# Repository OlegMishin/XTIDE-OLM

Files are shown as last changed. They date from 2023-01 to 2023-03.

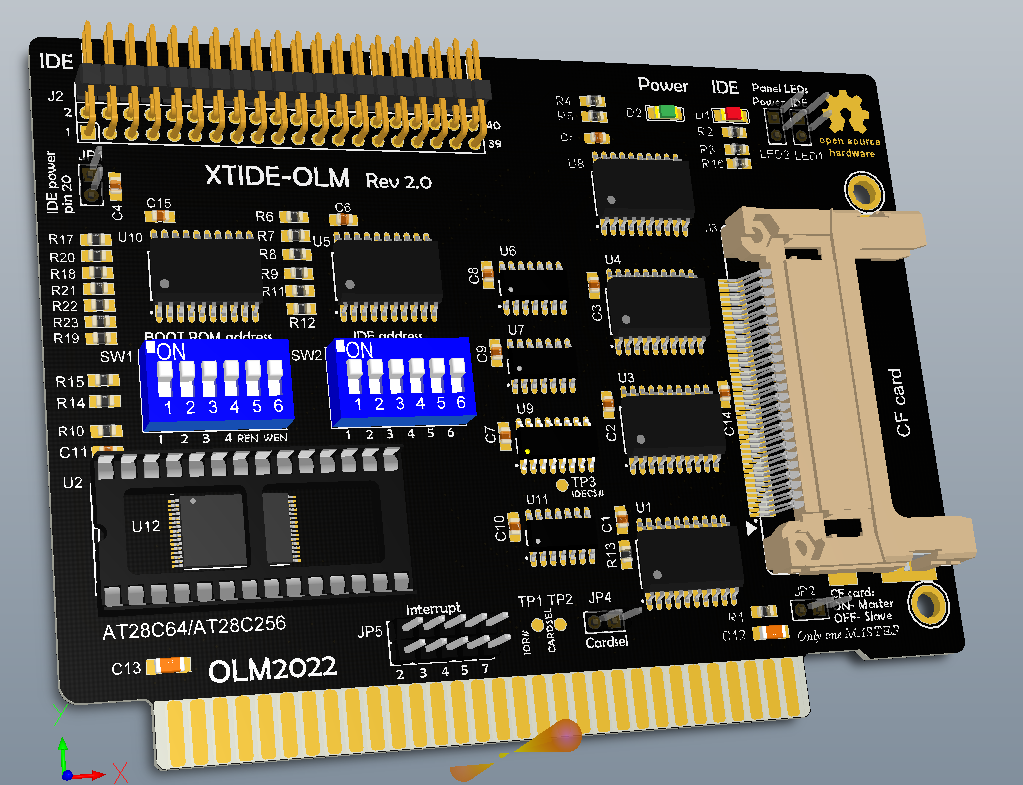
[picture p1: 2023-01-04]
3d.png

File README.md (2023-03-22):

# XTIDE-OLM
A Compact Flash to ISA bus adapter with XTIDE BIOS support

Based on Glitch Works XT-IDE: https://github.com/glitchwrks/xt_ide

So far tested with SST39F010 and AT28C64 Flash(writen with "xtidecfg.com") and 27C512 burned with TL866 programmer.
Works on PC-XT and PC-AT. Tested with 8088, 286, 386 and 486 computers. 

Designed for Keystone 9202 bracket. The bracket has no window for CF card, so it must be drilled manually.
Also the bracket can be 3D-printed. The 3D model is in "XTIDE_OLM-bracket.STL" file.

For 32K BIOS ROM R14 and R15 need to be be removed and mounted for 8K ROM (e.g. 2864).
There is no issue if R14 and R15 unmounted with 8K ROM, but in this case BIOS ROM window is 32K and configured by SW1.1 and SW1.2 only.

# XTIDE BIOS:
Can be obtained here: https://www.xtideuniversalbios.org/

# How to configure:
1. Set BIOS and I/O addresses by DIP switches SW1 and SW2.
2. Configure BIOS using XTIDECFG.
- Start XTIDECFG
- Select "Load BIOS from file" and load BIOS you want to flash.
- Go to "Configure XTIDE Universal BIOS". Usually I select "Auto configure"(CF card must be inserted) or manually configure it as needed.
- Go to "Flash EEPROM" and select "2864" or "SS39SFxx"(depends on installed Flash IC) and flash the BIOS.
- Reboot your computer.



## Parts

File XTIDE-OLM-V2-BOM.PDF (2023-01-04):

Bill of Materials | | XTIDE-OLM-V2
Revision | 2.0
Created by | OLM
Creation date | 01.01.2023 | 0:43:12
Print date | 01.01.2023 | 0:43:19
No. | QuantityDesignator | | Comment | Value | Part footprint | Part # | Manufacturer | Description
0 | 13 | C1, C2, C3, C4, C5, C6, C7, C8, C9, C10, C11, C14, C15 | Capacitor | 100nF | 0805 | K104K15X7RF5TH5 | Vishay Intertech | Ceramic capacitor SMD
1 | 2 | C12, C13 | Capacitor | 10uF | 1206 | CD1H106KC9IER2F100 | Dersonic | Ceramic capacitor SMD
2 | 1 | D1 | LED | 15-21/R6C-FQ1R1B/2T | 1206 | 15-21/R6C-FQ1R1B/2T | Everlight Elec | LED SMD 1206 Red
3 | 1 | D2 | LED | 24-21/G6C-BM1N2L/2A | 1206 | 24-21/G6C-BM1N2L/2A | Everlight Elec | LED SMD 1206 Green
4 | 1 | J3 | CF card socket | CFH-38690R | CF_CARD | CFH-38690R | UMAX | Compact Flash Card Socket
5 | 3 | R1, R4, R5 | Resistor | 1k | 0805 | ERJ6GEYJ102V | Panasonic | Resistor SMD 0805
6 | 16 | R2, R6, R7, R8, R9, R10, R11, R12, R13, R17, R18, R19, R20, R21, R22, R23 | Resistor | 10k | 0805 | ERJ6GEYJ103V | Panasonic | Resistor SMD 0805
7 | 1 | R3 | Resistor | 0R | 0805 | AC0805FR-070RL | YAGEO | Resistor SMD 0805
8 | 1 | R16 | Resistor | 470 | 0805 | ERJ6GEYJ471V | Panasonic | Resistor SMD 0805
9 | 2 | U1, U8 | 74HCT245 | SN74HCT245DWR | SOIC-20 | SN74HCT245DWR | Texas Instruments | 8-bit 3-State Non-Inverting Bus Transceiver
10 | 2 | U3, U4 | 74HCT573 | 74HCT573D,653 | SOIC-20 | 74HCT573D,653 | Nexperia | 8-bit 3-State Non-Inverting Latch
11 | 2 | U5, U10 | 74HCT688 | CD74HCT688M96 | SOIC-20 | CD74HCT688M96 | Texas Instruments | 8-Bit Equality Comparator
12 | 1 | U6 | 74HCT32 | SN74HCT32DR | SOIC-14 | SN74HCT32DR | Texas Instruments | Quadruple 2-Input Positive-OR Gate
13 | 2 | U7, U11 | 74HCT04 | 74HCT04D,653 | SOIC-14 | 74HCT04D,653 | Nexperia | Hex Inverter with LSTTL Compatible Inputs
14 | 1 | U9 | 74HCT138 | SN74HCT138DR | SOIC-16 | SN74HCT138DR | Texas Instruments | 1-of-8 Decoder/Demultiplexer
15 | 1 | U12 | SST39SF010A | SST39SF010A-55-4I-WHE | TSOP32 | SST39SF010A-55-4I-WHE | Micron Technology Inc | 1Mb FLASH MEMORY

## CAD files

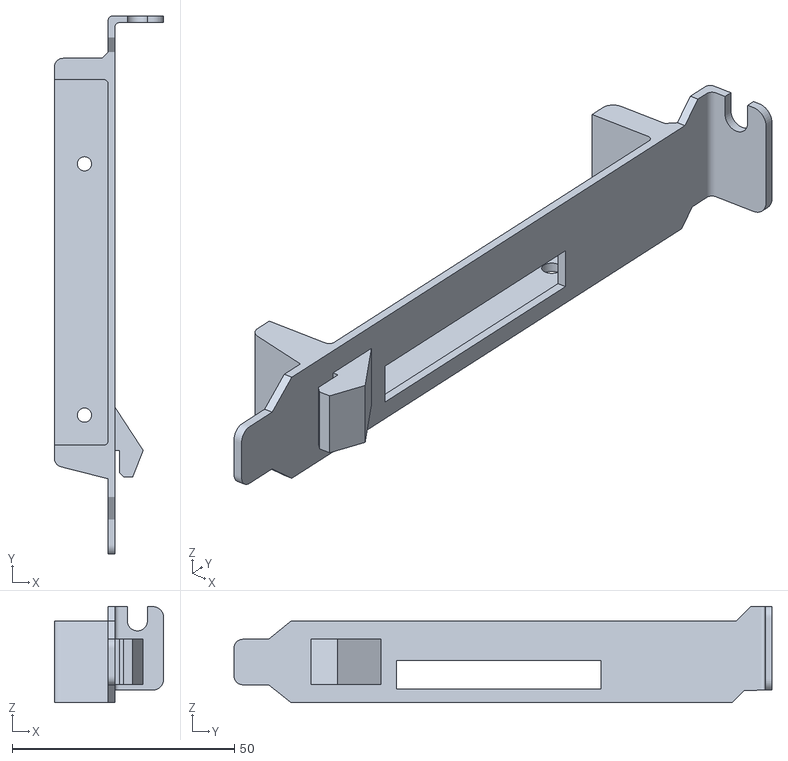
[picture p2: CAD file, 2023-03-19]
XTIDE_OLM-bracket.STL
24.6 x 121.0 x 21.6

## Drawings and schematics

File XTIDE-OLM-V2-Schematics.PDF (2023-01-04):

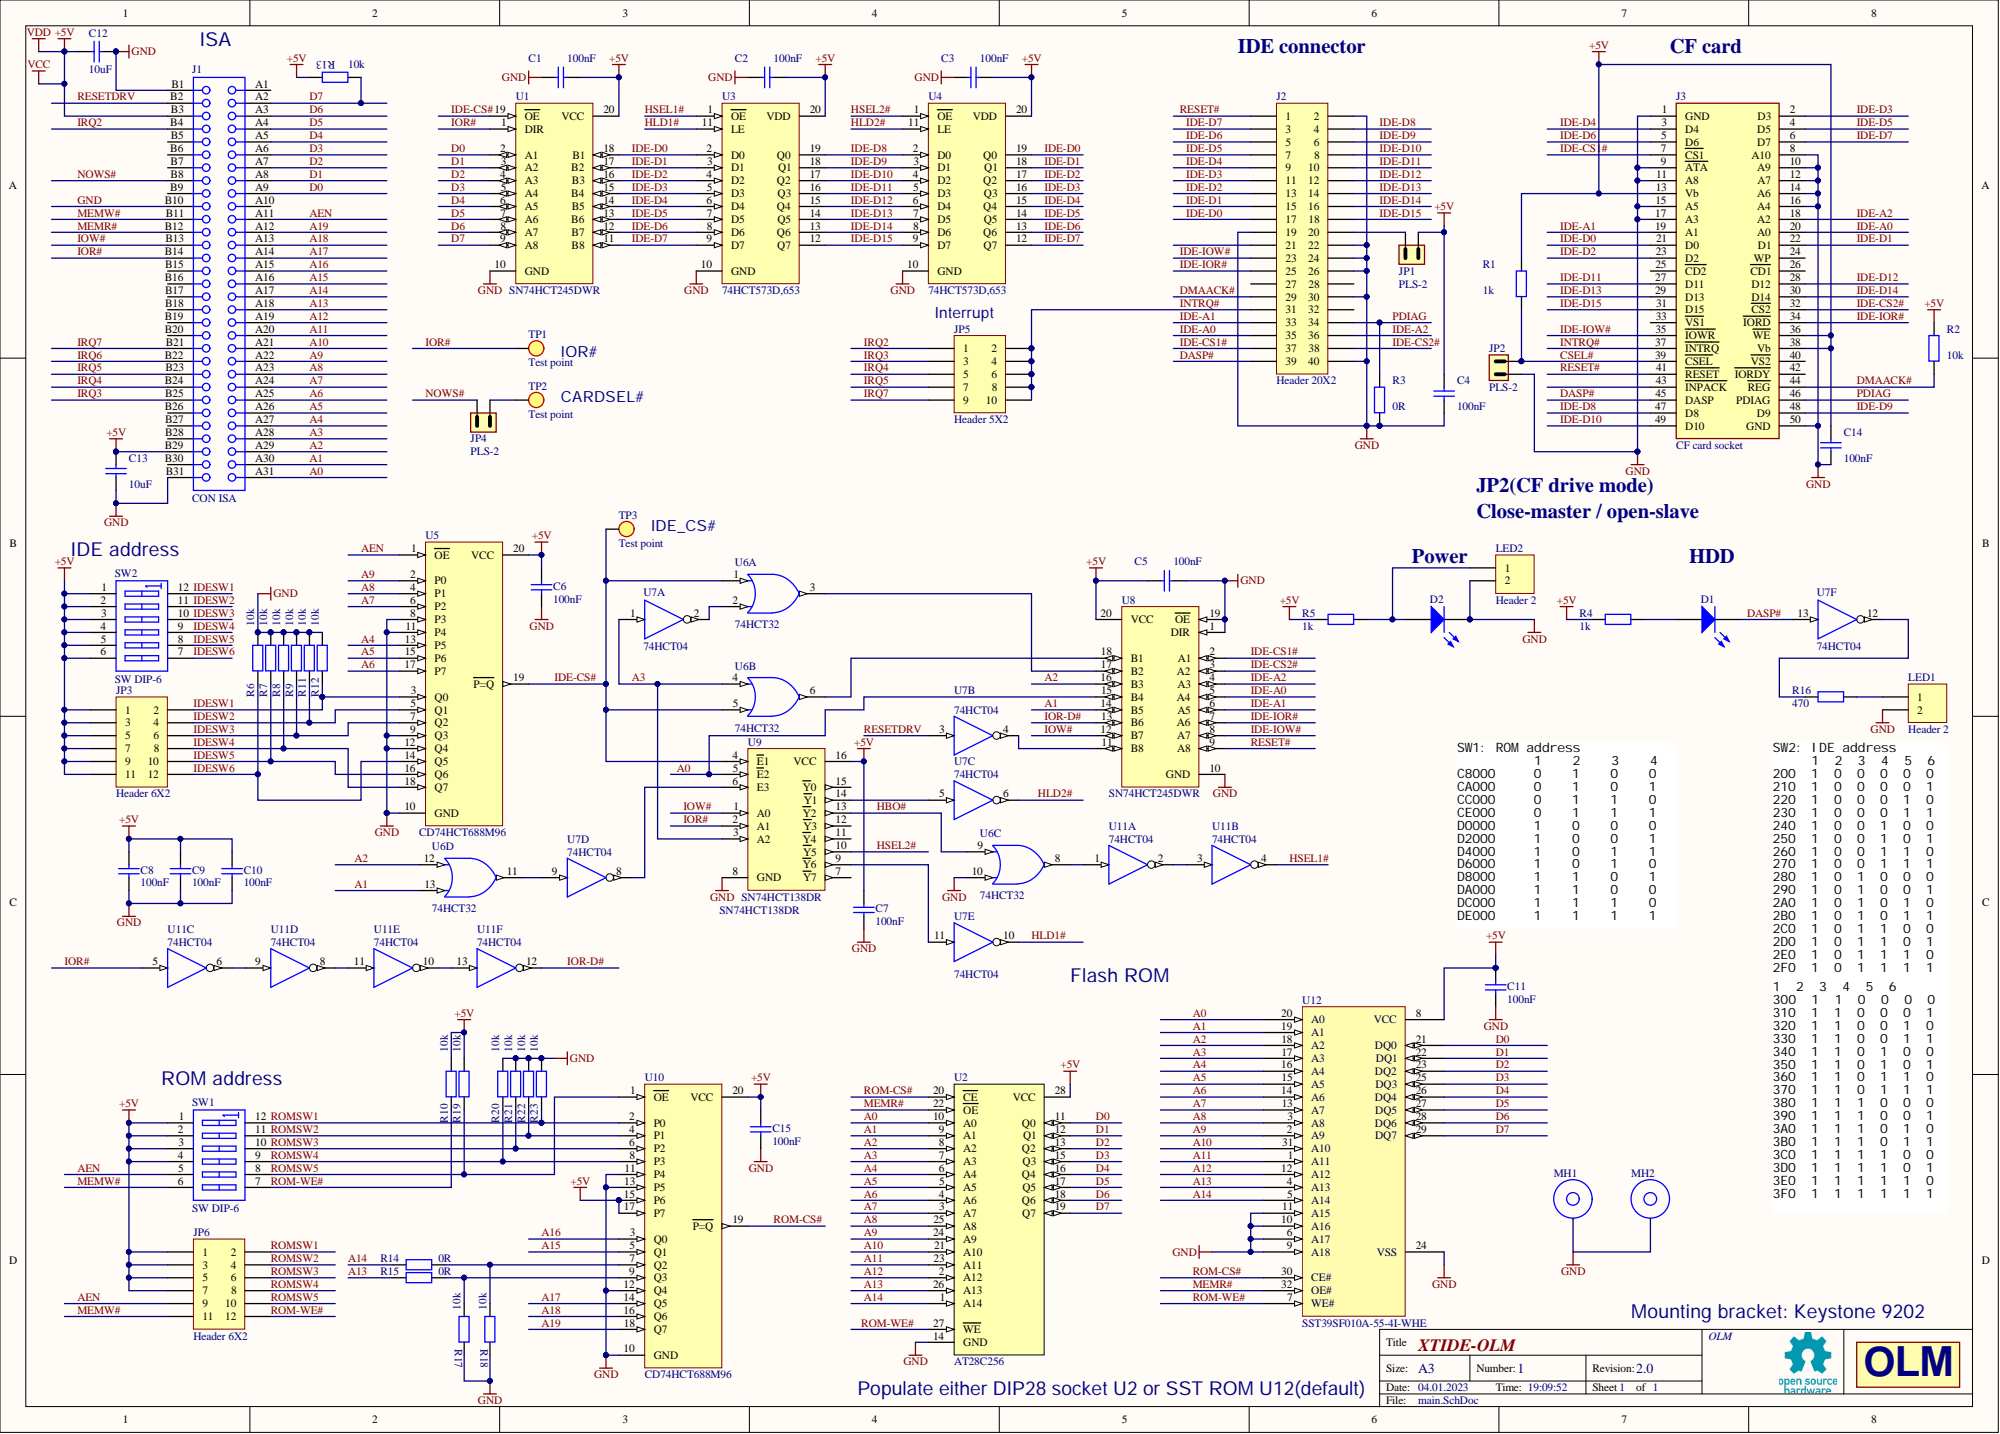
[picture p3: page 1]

JP2(CF drive mode)
Close-master / open-slave

IDESW6 | Q6 16 | E2 5 E3 6

GND
Populate either DIP28 socket U2 or SST ROM U12(default)

Size: | Number: 1 | Revision: 2.0
Date: 04.01.2023 Time: 19:09:52 | | Sheet 1 of 1

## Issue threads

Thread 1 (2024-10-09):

Pick & Place

oXL0C0Xo, 2024-10-09:
Hello, I just wanted to see if you would be willing to generate the CPL file for manufacturing. I wanted to try and get some of these made up, but I cant figure out how to do it from the gerber files alone. Thank you for your time creating this awesome project, hope to hear back from you.

Thanks,
Bryon

OlegMishin, 2024-10-09:
Hi Bryon,

Please try this one. Even if it is for rev 2.1, it should match 2.0 pcb.

Br
Oleg

[XTIDE-OLM-V21-PnP.csv](https://github.com/user-attachments/files/17310769/XTIDE-OLM-V21-PnP.csv)

oXL0C0Xo, 2024-10-09:
I appreciate it! I'll let you know how it turns out
